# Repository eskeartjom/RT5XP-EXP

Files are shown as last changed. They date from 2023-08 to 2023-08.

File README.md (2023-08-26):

# RT5XP-EXP
A input expander for the RetroTINK 5X-Pro

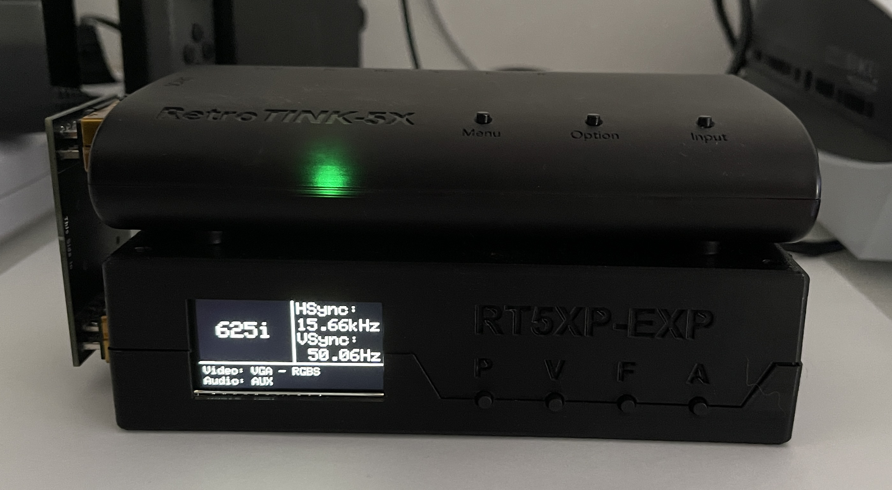
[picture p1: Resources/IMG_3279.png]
RT5XP-EXP

RT5XP-EXP Top

---
## Introduction
The RT5XP-EXP is a purpose build device to extend the input capabilities of the RetroTINK 5X-Pro.

### Input
The Following video signals are supported:

- SCART (RGBS, RGsB, YPbPr)
- Component (YPbPr, RGsB)
- VGA (RGBHV, RGBS, RGsB, YPbPr)

Audio signals can be input as RCA, 3.5mm Jack or SCART and can be selected independently of the video signal.

The sync on scart and component inputs need to be attenuated 75 Ohm signals.
Scart also supports a attenuated CSync signal as the sync input.

The VGA input only supports TTL signals on the sync pins. When using RGsB/YPbPr these need attenuated correctly (which they should be in the first place). VGA also supports TTL CSync on pin 13.

**Input Resolution***: 240p - 1080i

Switching between resolutions is seamless.

### Output

The RT5XP-EXP outputs the signal in RGBS format out of the left scart connector. This signal should be safe to plug into any scart device. The sync signal is a attenuated csync signal.

**Output Resolution***: 240p - 1080i

*Tested on a RetroTINK 5X-Pro and a OSSC

### Display
The big area on the top left shows the line count* of the current input.
The area on the right shows the measured* horizontal and vertical sync signal.
At the bottom the display shows the currenty used and video and audio input.

*The values may not be 100% accurate but close enough.

### Buttons
- P: Cycles thought presets.
- V: Cycles thought different video inputs.
- F: Cycles thought different formats of the current video input.
- A: Cycles thought different audio inputs.

Holding the P button opens a menu. This menu is still WIP.

---
## Hardware
The hardware consists of following things:

- [Main PCB](./Hardware/MainPCB)
- [Display bracked PCB](./Hardware/DisplayPCB)
- [Case](./Hardware/Case)
- [(Optional) SCART PCB](./Hardware/InterconnectPCB)
- [Display](https://www.adafruit.com/product/5394)

---
## Firmware
NOTE: Is still WIP but usable for the basics
- [Firmware](./Firmware)

The firmware is based on a ATmega4809.
I used the Arduino IDE with following libraries:
- [MegaCoreX](https://github.com/MCUdude/MegaCoreX)
- [Adafruit_ST7789](https://github.com/adafruit/Adafruit-ST7735-Library)
- [Adafruit_GFX](https://learn.adafruit.com/adafruit-gfx-graphics-library/overview)

The microcontroller can be flashed via the usb connection.

---
## Misc
Technically the RT5XP-EXP should be support 1080p resolution but i could not test it.

---
## Known issues
On sharp edges there is a purple "color bending". In game this isn't that noticable or might not be noticed at all.

Color Bending

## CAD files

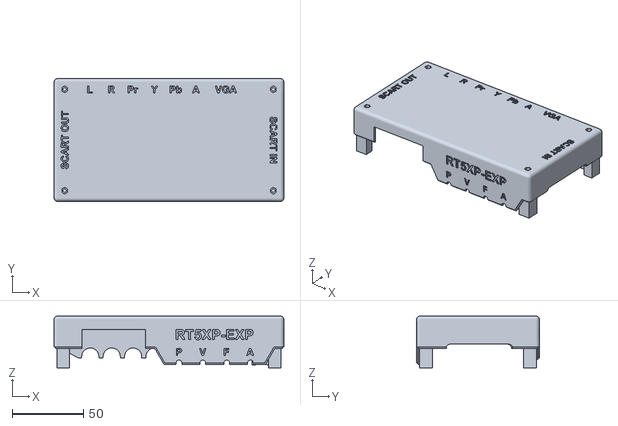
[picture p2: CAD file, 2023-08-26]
Hardware/Case/RT5XP-Top.stl
161.0 x 86.0 x 36.4

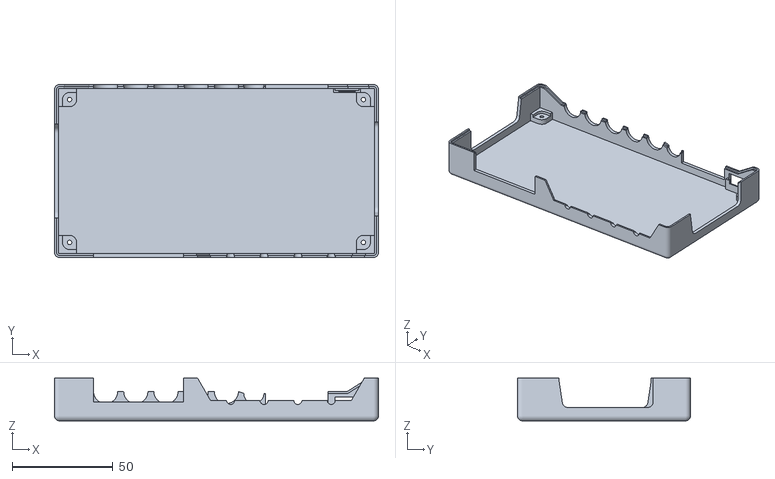
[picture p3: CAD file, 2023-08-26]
Hardware/Case/RT5XP-Bottom.stl
161.0 x 86.0 x 21.2

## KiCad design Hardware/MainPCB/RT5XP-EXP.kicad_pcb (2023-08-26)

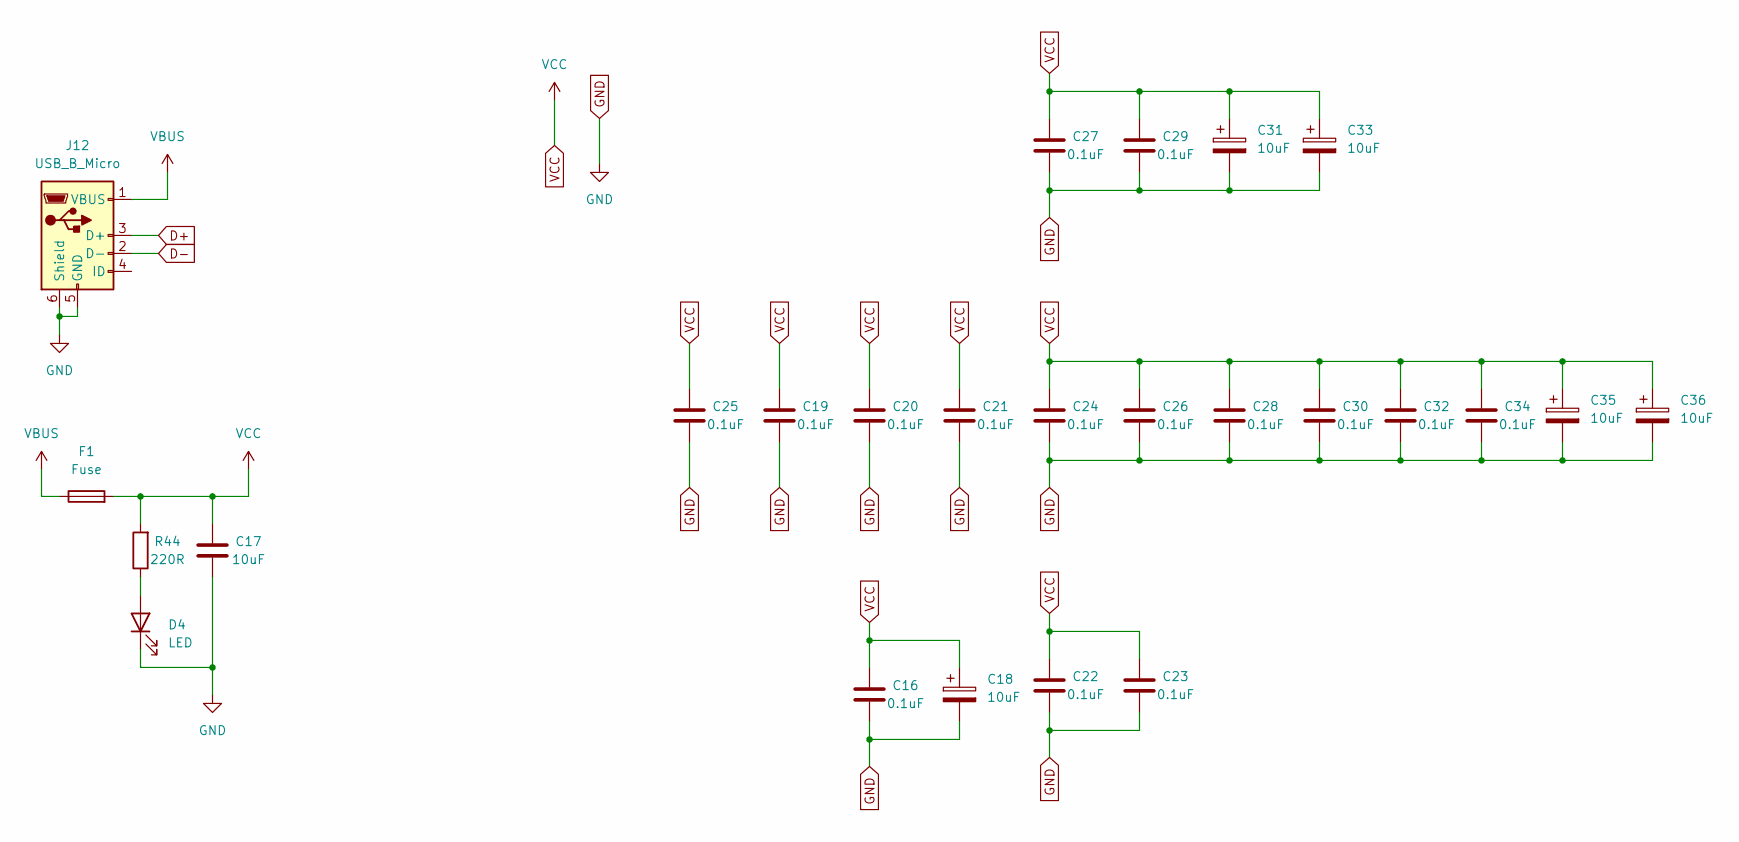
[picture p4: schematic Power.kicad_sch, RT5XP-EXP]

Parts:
C16, C19, C20, C21, C22, C23, C24, C25, C26, C27, C28, C29, C30, C32, C34: 0.1uF; C_0603_1608Metric
C17: 10uF; C_0805_2012Metric
C18, C31, C33, C35, C36: 10uF; C_0603_1608Metric
D4: LED; LED_0603_1608Metric
F1: Fuse; Fuse_1210_3225Metric
J12: USB_B_Micro; USB_Micro-B_Molex-105017-0001
R44: 220R; R_0603_1608Metric

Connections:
D+: J12.3 (D+); also elsewhere on the board
D-: J12.2 (D-); also elsewhere on the board
GND: C16.1, C17.1, C18.2, C19.1, C20.1, C21.1, C22.1, C23.1, C24.1, C25.1, C26.1, C27.1, C28.1, C29.1, C30.1, C31.2, C32.1, C33.2, C34.1, C35.2, C36.2, D4.1 (K), J12.5 (GND), J12.6 (Shield); also elsewhere on the board
unnamed: D4.2 (A), R44.1
VBUS: F1.1, J12.1 (VBUS)
VCC: C16.2, C17.2, C18.1, C19.2, C20.2, C21.2, C22.2, C23.2, C24.2, C25.2, C26.2, C27.2, C28.2, C29.2, C30.2, C31.1, C32.2, C33.1, C34.2, C35.1, C36.1, F1.2, R44.2; also elsewhere on the board

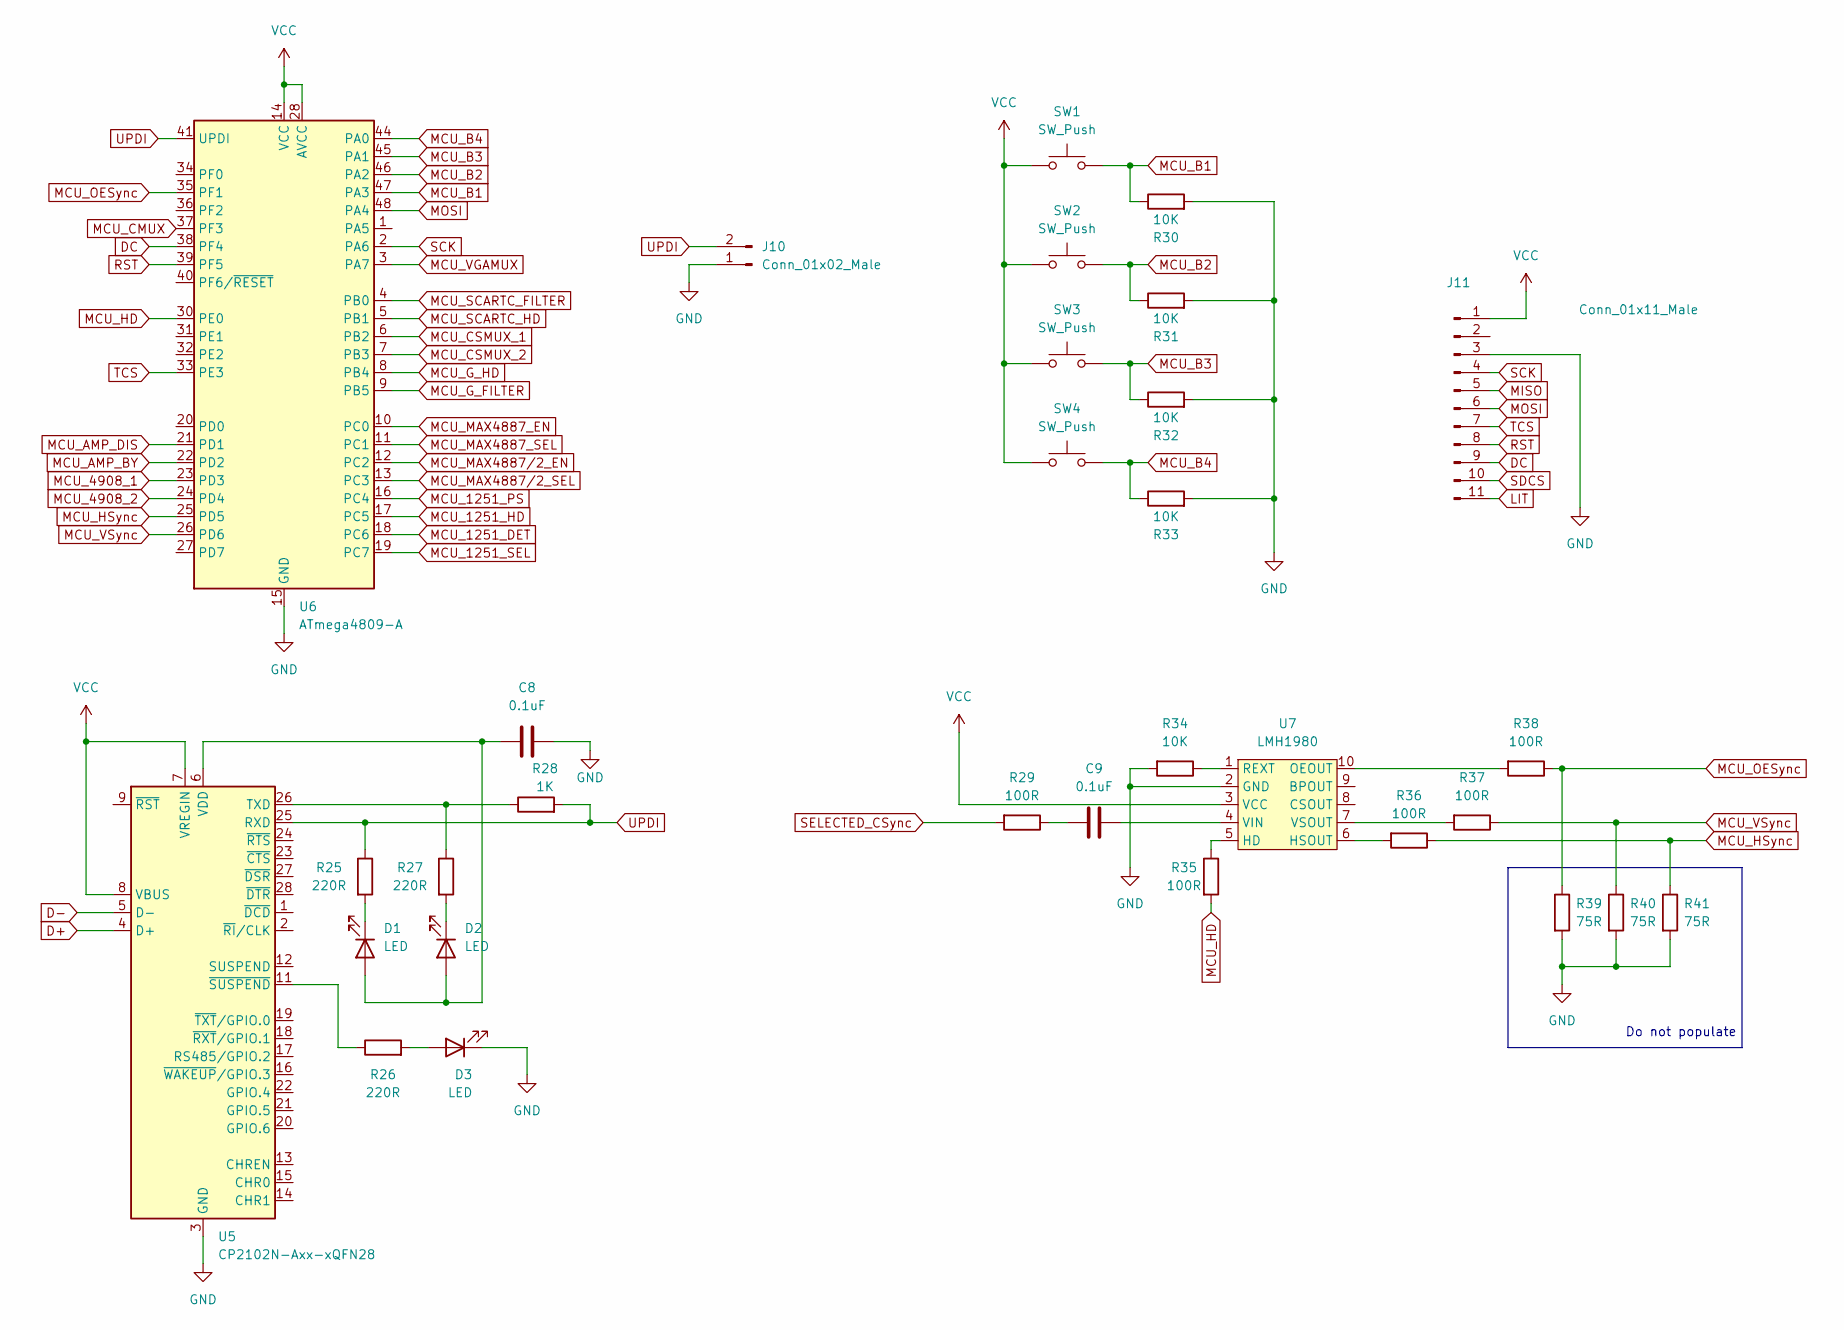
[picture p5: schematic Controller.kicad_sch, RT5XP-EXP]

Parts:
C8, C9: 0.1uF; C_0603_1608Metric
D1, D2, D3: LED; LED_0603_1608Metric
J10: Conn_01x02_Male; PinSocket_1x02_P2.54mm_Vertical
J11: Conn_01x11_Male; PinHeader_1x11_P2.54mm_Horizontal
R25, R26, R27: 220R; R_0603_1608Metric
R28: 1K; R_0603_1608Metric
R29, R35, R36, R37, R38: 100R; R_0603_1608Metric
R30, R31, R32, R33, R34: 10K; R_0603_1608Metric
R39, R40, R41: 75R; R_0603_1608Metric
SW1, SW2, SW3, SW4: SW_Push; SW_Tactile_SPST_Angled_PTS645Vx83-2LFS
U5: CP2102N-Axx-xQFN28; QFN-28-1EP_5x5mm_P0.5mm_EP3.35x3.35mm
U6: ATmega4809-A; TQFP-48_7x7mm_P0.5mm
U7: LMH1980; VSSOP-10_3x3mm_P0.5mm

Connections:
D+: U5.4 (D+); also elsewhere on the board
D-: U5.5 (D-); also elsewhere on the board
DC: J11.9, U6.38 (PF4)
GND: C8.1, D3.1 (K), J10.1, J11.3, R30.2, R31.2, R32.2, R33.2, R34.2, R39.2, R40.2, R41.2, U5.3 (GND), U5.29 (GND), U6.15 (GND), U6.29 (GND), U6.43 (GND), U7.2 (GND); also elsewhere on the board
LIT: J11.11
MCU_1251_DET: U6.18 (PC6); also elsewhere on the board
MCU_1251_HD: U6.17 (PC5); also elsewhere on the board
MCU_1251_PS: U6.16 (PC4); also elsewhere on the board
MCU_1251_SEL: U6.19 (PC7); also elsewhere on the board
MCU_4908_1: U6.23 (PD3); also elsewhere on the board
MCU_4908_2: U6.24 (PD4); also elsewhere on the board
MCU_AMP_BY: U6.22 (PD2); also elsewhere on the board
MCU_AMP_DIS: U6.21 (PD1); also elsewhere on the board
MCU_B1: R30.1, SW1.2, U6.47 (PA3)
MCU_B2: R31.1, SW2.2, U6.46 (PA2)
MCU_B3: R32.1, SW3.2, U6.45 (PA1)
MCU_B4: R33.1, SW4.2, U6.44 (PA0)
MCU_CMUX: U6.37 (PF3); also elsewhere on the board
MCU_CSMUX_1: U6.6 (PB2); also elsewhere on the board
MCU_CSMUX_2: U6.7 (PB3); also elsewhere on the board
MCU_G_FILTER: U6.9 (PB5); also elsewhere on the board
MCU_G_HD: U6.8 (PB4); also elsewhere on the board
MCU_HD: R35.2, U6.30 (PE0)
MCU_HSync: R36.1, R41.1, U6.25 (PD5)
MCU_MAX4887_EN: U6.10 (PC0); also elsewhere on the board
MCU_MAX4887_SEL: U6.11 (PC1); also elsewhere on the board
MCU_MAX4887/2_EN: U6.12 (PC2); also elsewhere on the board
MCU_MAX4887/2_SEL: U6.13 (PC3); also elsewhere on the board
MCU_OESync: R38.1, R39.1, U6.35 (PF1)
MCU_SCARTC_FILTER: U6.4 (PB0); also elsewhere on the board
MCU_SCARTC_HD: U6.5 (PB1); also elsewhere on the board
MCU_VGAMUX: U6.3 (PA7); also elsewhere on the board
MCU_VSync: R37.1, R40.1, U6.26 (PD6)
MISO: J11.5
MOSI: J11.6, U6.48 (PA4)
unnamed: C8.2, D1.2 (A), D2.2 (A), U5.6 (VDD)
unnamed: C9.1, R29.1
unnamed: C9.2, U7.4 (VIN)
unnamed: D1.1 (K), R25.2
unnamed: D2.1 (K), R27.2
unnamed: D3.2 (A), R26.2
unnamed: R26.1, U5.11 (~SUSPEND)
unnamed: R27.1, R28.1, U5.26 (TXD)
unnamed: R34.1, U7.1 (REXT)
unnamed: R35.1, U7.5 (HD)
unnamed: R36.2, U7.6 (HSOUT)
unnamed: R37.2, U7.7 (VSOUT)
unnamed: R38.2, U7.10 (OEOUT)
RST: J11.8, U6.39 (PF5)
SCK: J11.4, U6.2 (PA6)
SDCS: J11.10
SELECTED_CSync: R29.2; also elsewhere on the board
TCS: J11.7, U6.33 (PE3)
UPDI: J10.2, R25.1, R28.2, U5.25 (RXD), U6.41 (UPDI)
VCC: J11.1, SW1.1, SW2.1, SW3.1, SW4.1, U5.7 (VREGIN), U5.8 (VBUS), U6.14 (VCC), U6.28 (AVCC), U6.42 (VCC), U7.3 (VCC); also elsewhere on the board

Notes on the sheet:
Do not populate

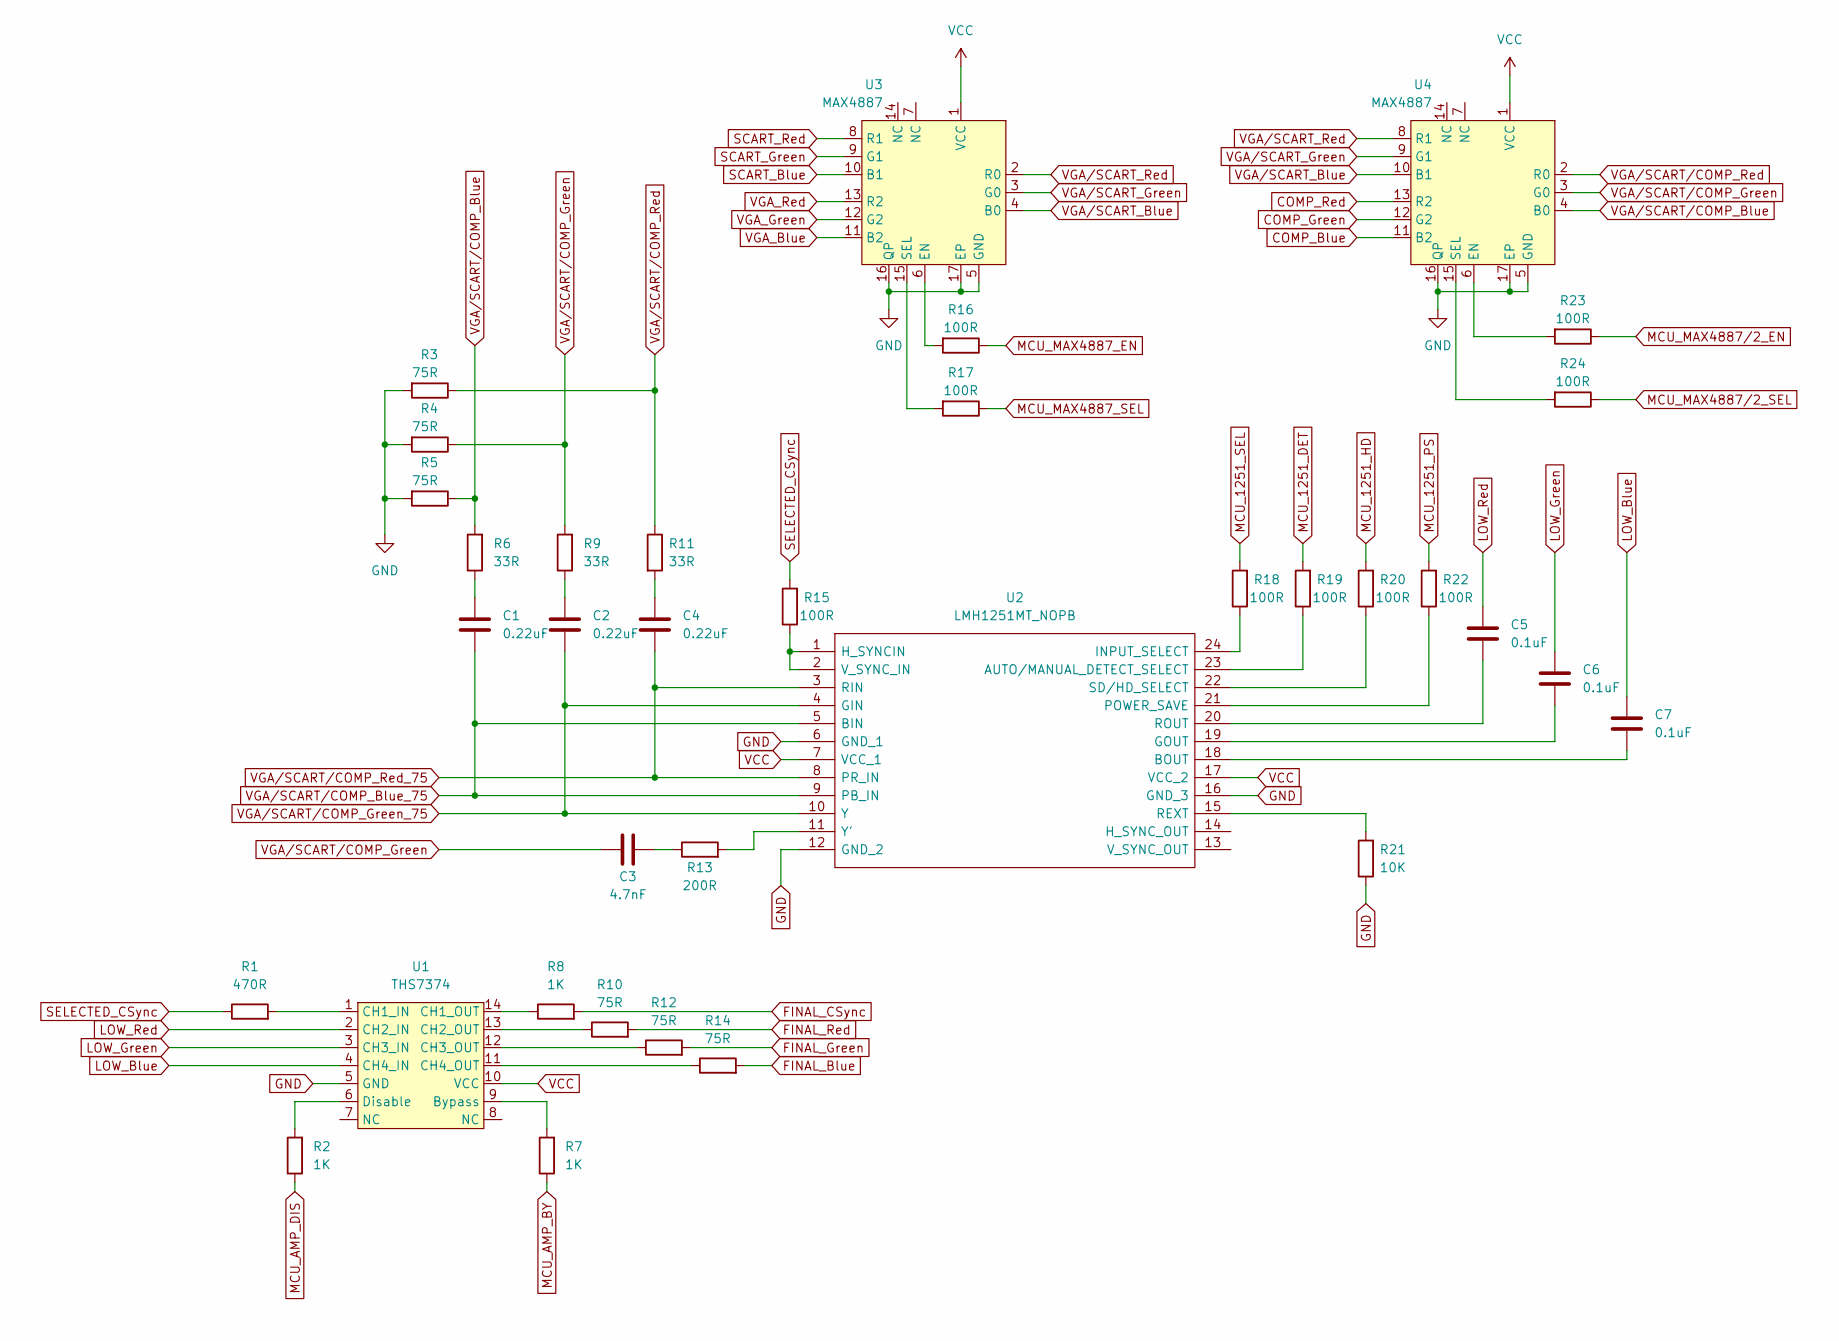
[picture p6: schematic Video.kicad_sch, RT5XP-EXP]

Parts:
C1, C2, C4: 0.22uF; C_0603_1608Metric
C3: 4.7nF; C_0603_1608Metric
C5, C6, C7: 0.1uF; C_0603_1608Metric
R1: 470R; R_0603_1608Metric
R2, R7, R8: 1K; R_0603_1608Metric
R3, R4, R5, R10, R12, R14: 75R; R_0603_1608Metric
R6, R9, R11: 33R; R_0603_1608Metric
R13: 200R; R_0603_1608Metric
R15, R16, R17, R18, R19, R20, R22, R23, R24: 100R; R_0603_1608Metric
R21: 10K; R_0603_1608Metric
U1: THS7374; TSSOP-14_4.4x5mm_P0.65mm
U2: LMH1251MT_NOPB; TSSOP-24_4.4x7.8mm_P0.65mm; Mouser Part Number 926-LMH1251MT/NOPB
U3, U4: MAX4887; TQFN-16-1EP_3x3mm_P0.5mm_EP1.23x1.23mm

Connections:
COMP_Blue: U4.11 (B2); also elsewhere on the board
COMP_Green: U4.12 (G2); also elsewhere on the board
COMP_Red: U4.13 (R2); also elsewhere on the board
FINAL_Blue: R14.2; also elsewhere on the board
FINAL_CSync: R8.2; also elsewhere on the board
FINAL_Green: R12.2; also elsewhere on the board
FINAL_Red: R10.2; also elsewhere on the board
GND: R3.2, R4.2, R5.2, R21.1, U1.5 (GND), U2.6 (GND_1), U2.12 (GND_2), U2.16 (GND_3), U3.5 (GND), U3.16 (QP), U3.17 (EP), U4.5 (GND), U4.16 (QP), U4.17 (EP); also elsewhere on the board
LOW_Blue: C7.2, U1.4 (CH4_IN)
LOW_Green: C6.2, U1.3 (CH3_IN)
LOW_Red: C5.2, U1.2 (CH2_IN)
MCU_1251_DET: R19.2; also elsewhere on the board
MCU_1251_HD: R20.2; also elsewhere on the board
MCU_1251_PS: R22.2; also elsewhere on the board
MCU_1251_SEL: R18.2; also elsewhere on the board
MCU_AMP_BY: R7.1; also elsewhere on the board
MCU_AMP_DIS: R2.1; also elsewhere on the board
MCU_MAX4887_EN: R16.1; also elsewhere on the board
MCU_MAX4887_SEL: R17.1; also elsewhere on the board
MCU_MAX4887/2_EN: R23.1; also elsewhere on the board
MCU_MAX4887/2_SEL: R24.1; also elsewhere on the board
unnamed: C1.2, R6.1
unnamed: C2.2, R9.1
unnamed: C3.2, R13.1
unnamed: C4.2, R11.2
unnamed: C5.1, U2.20 (ROUT)
unnamed: C6.1, U2.19 (GOUT)
unnamed: C7.1, U2.18 (BOUT)
unnamed: R1.2, U1.1 (CH1_IN)
unnamed: R2.2, U1.6 (Disable)
unnamed: R7.2, U1.9 (Bypass)
unnamed: R8.1, U1.14 (CH1_OUT)
unnamed: R10.1, U1.13 (CH2_OUT)
unnamed: R12.1, U1.12 (CH3_OUT)
unnamed: R13.2, U2.11 (Y')
unnamed: R14.1, U1.11 (CH4_OUT)
unnamed: R15.1, U2.1 (H_SYNCIN), U2.2 (V_SYNC_IN)
unnamed: R16.2, U3.6 (EN)
unnamed: R17.2, U3.15 (SEL)
unnamed: R18.1, U2.24 (INPUT_SELECT)
unnamed: R19.1, U2.23 (AUTO/MANUAL_DETECT_SELECT)
unnamed: R20.1, U2.22 (SD/HD_SELECT~)
unnamed: R21.2, U2.15 (REXT)
unnamed: R22.1, U2.21 (POWER_SAVE)
unnamed: R23.2, U4.6 (EN)
unnamed: R24.2, U4.15 (SEL)
SCART_Blue: U3.10 (B1); also elsewhere on the board
SCART_Green: U3.9 (G1); also elsewhere on the board
SCART_Red: U3.8 (R1); also elsewhere on the board
SELECTED_CSync: R1.1, R15.2; also elsewhere on the board
VCC: U1.10 (VCC), U2.7 (VCC_1), U2.17 (VCC_2), U3.1 (VCC), U4.1 (VCC); also elsewhere on the board
VGA_Blue: U3.11 (B2); also elsewhere on the board
VGA_Green: U3.12 (G2); also elsewhere on the board
VGA_Red: U3.13 (R2); also elsewhere on the board
VGA/SCART_Blue: U3.4 (B0), U4.10 (B1)
VGA/SCART_Green: U3.3 (G0), U4.9 (G1)
VGA/SCART_Red: U3.2 (R0), U4.8 (R1)
VGA/SCART/COMP_Blue: R5.1, R6.2, U4.4 (B0)
VGA/SCART/COMP_Blue_75: C1.1, U2.5 (BIN), U2.9 (PB_IN)
VGA/SCART/COMP_Green: C3.1, R4.1, R9.2, U4.3 (G0)
VGA/SCART/COMP_Green_75: C2.1, U2.4 (GIN), U2.10 (Y); also elsewhere on the board
VGA/SCART/COMP_Red: R3.1, R11.1, U4.2 (R0)
VGA/SCART/COMP_Red_75: C4.1, U2.3 (RIN), U2.8 (PR_IN)

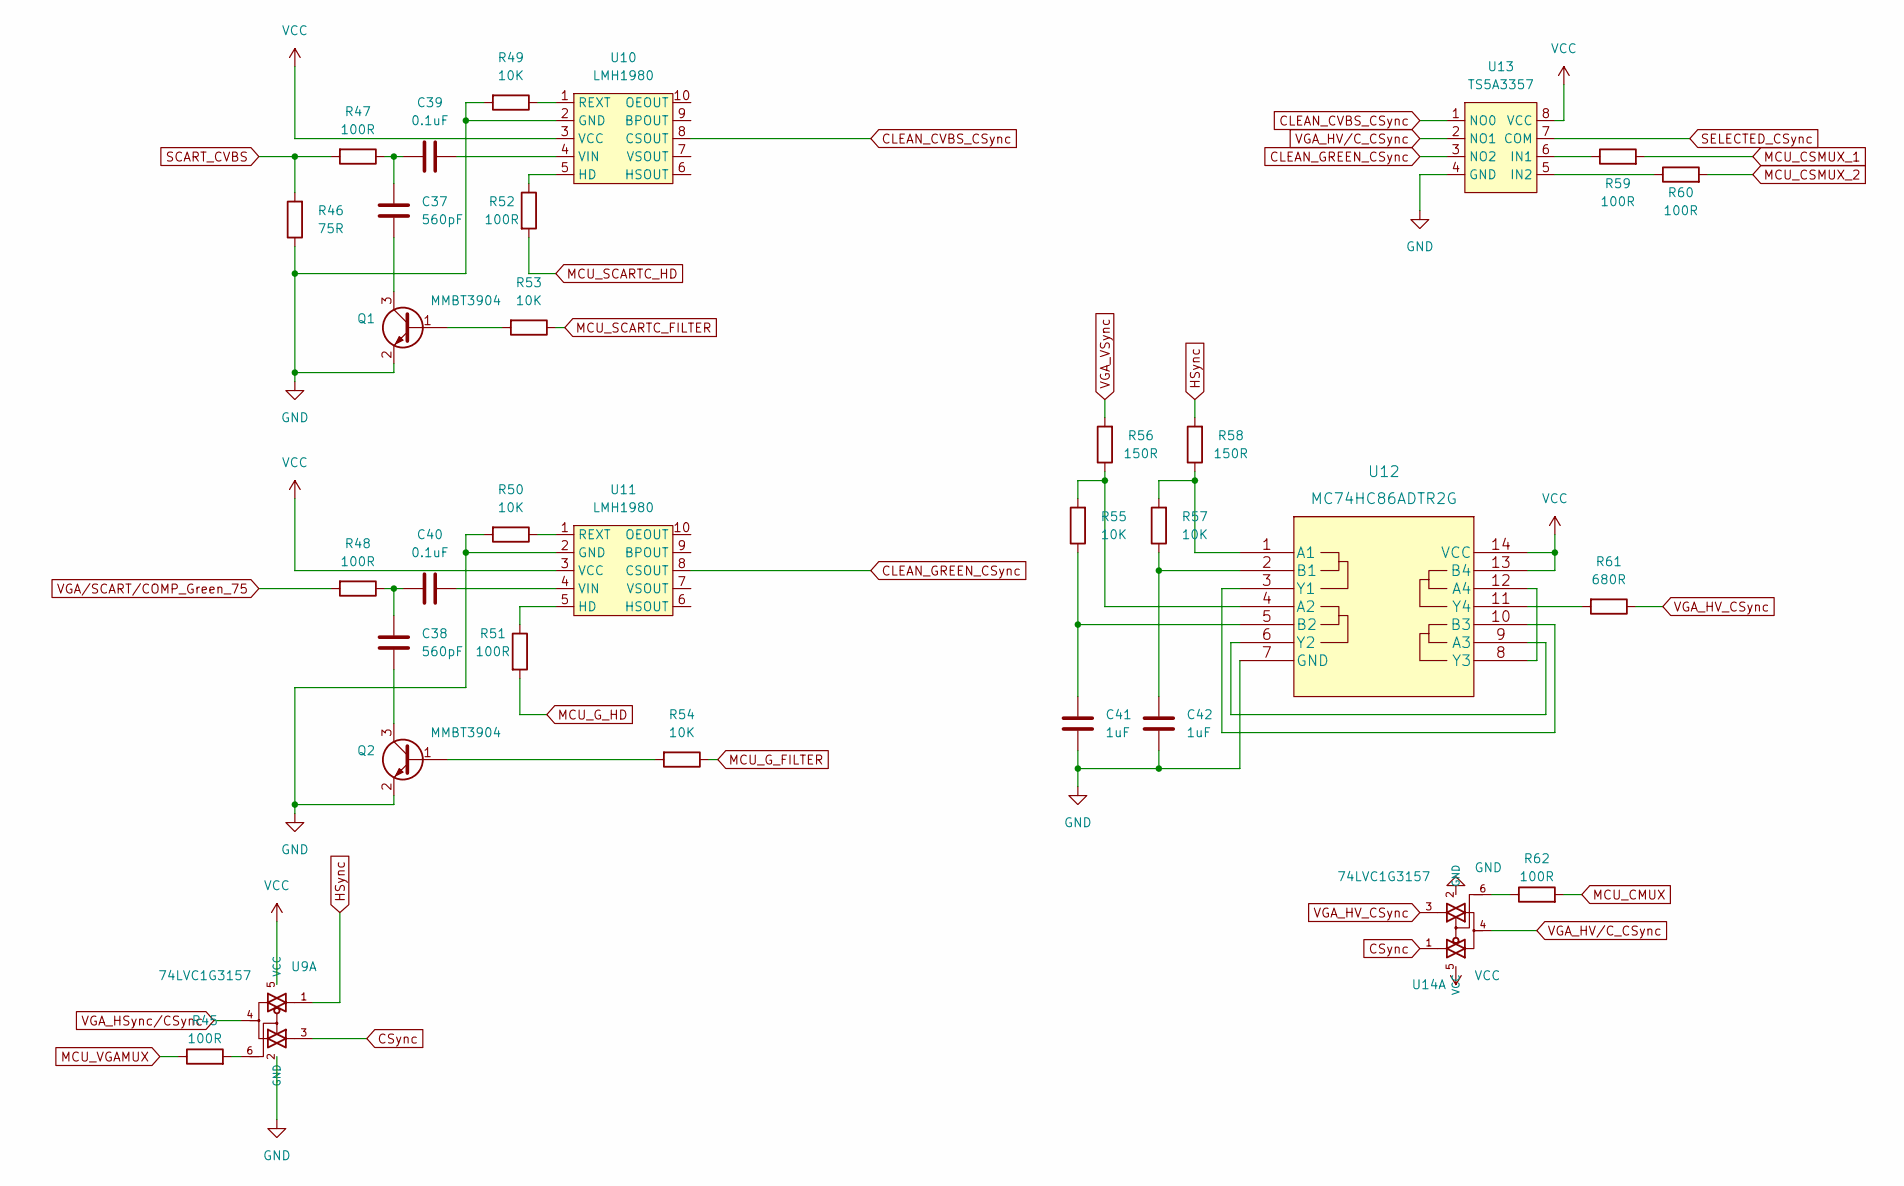
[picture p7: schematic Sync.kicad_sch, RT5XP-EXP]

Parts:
C37, C38: 560pF; C_0603_1608Metric
C39, C40: 0.1uF; C_0603_1608Metric
C41, C42: 1uF; C_0603_1608Metric
Q1, Q2: MMBT3904; SOT-23
R45, R47, R48, R51, R52, R59, R60, R62: 100R; R_0603_1608Metric
R46: 75R; R_0603_1608Metric
R49, R50, R53, R54, R55, R57: 10K; R_0603_1608Metric
R56, R58: 150R; R_0603_1608Metric
R61: 680R; R_0603_1608Metric
U9, U14: 74LVC1G3157; TSOT-23-6
U10, U11: LMH1980; VSSOP-10_3x3mm_P0.5mm
U12: MC74HC86ADTR2G; TSSOP-14_4.4x5mm_P0.65mm
U13: TS5A3357; VSSOP-8_2.3x2mm_P0.5mm

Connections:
CLEAN_CVBS_CSync: U10.8 (CSOUT), U13.1 (NO0)
CLEAN_GREEN_CSync: U11.8 (CSOUT), U13.3 (NO2)
CSync: U9.3, U14.1
GND: C41.1, C42.1, Q1.2 (E), Q2.2 (E), R46.1, R49.2, R50.2, U9.2 (GND), U10.2 (GND), U11.2 (GND), U12.7 (GND), U13.4 (GND), U14.2 (GND); also elsewhere on the board
HSync: R58.2, U9.1
MCU_CMUX: R62.2; also elsewhere on the board
MCU_CSMUX_1: R59.2; also elsewhere on the board
MCU_CSMUX_2: R60.2; also elsewhere on the board
MCU_G_FILTER: R54.1; also elsewhere on the board
MCU_G_HD: R51.2; also elsewhere on the board
MCU_SCARTC_FILTER: R53.1; also elsewhere on the board
MCU_SCARTC_HD: R52.2; also elsewhere on the board
MCU_VGAMUX: R45.1; also elsewhere on the board
unnamed: C37.1, Q1.3 (C)
unnamed: C37.2, C39.1, R47.1
unnamed: C38.1, Q2.3 (C)
unnamed: C38.2, C40.1, R48.1
unnamed: C39.2, U10.4 (VIN)
unnamed: C40.2, U11.4 (VIN)
unnamed: C41.2, R55.1, U12.5 (B2)
unnamed: C42.2, R57.1, U12.2 (B1)
unnamed: Q1.1 (B), R53.2
unnamed: Q2.1 (B), R54.2
unnamed: R45.2, U9.6
unnamed: R49.1, U10.1 (REXT)
unnamed: R50.1, U11.1 (REXT)
unnamed: R51.1, U11.5 (HD)
unnamed: R52.1, U10.5 (HD)
unnamed: R55.2, R56.1, U12.4 (A2)
unnamed: R57.2, R58.1, U12.1 (A1)
unnamed: R59.1, U13.6 (IN1)
unnamed: R60.1, U13.5 (IN2)
unnamed: R61.2, U12.11 (Y4)
unnamed: R62.1, U14.6
unnamed: U12.6 (Y2), U12.9 (A3)
unnamed: U12.3 (Y1), U12.10 (B3)
unnamed: U12.8 (Y3), U12.12 (A4)
SCART_CVBS: R46.2, R47.2; also elsewhere on the board
SELECTED_CSync: U13.7 (COM); also elsewhere on the board
VCC: U9.5 (VCC), U10.3 (VCC), U11.3 (VCC), U12.13 (B4), U12.14 (VCC), U13.8 (VCC), U14.5 (VCC); also elsewhere on the board
VGA_HSync/CSync: U9.4; also elsewhere on the board
VGA_HV_CSync: R61.1, U14.3
VGA_HV/C_CSync: U13.2 (NO1), U14.4
VGA_VSync: R56.2; also elsewhere on the board
VGA/SCART/COMP_Green_75: R48.2; also elsewhere on the board

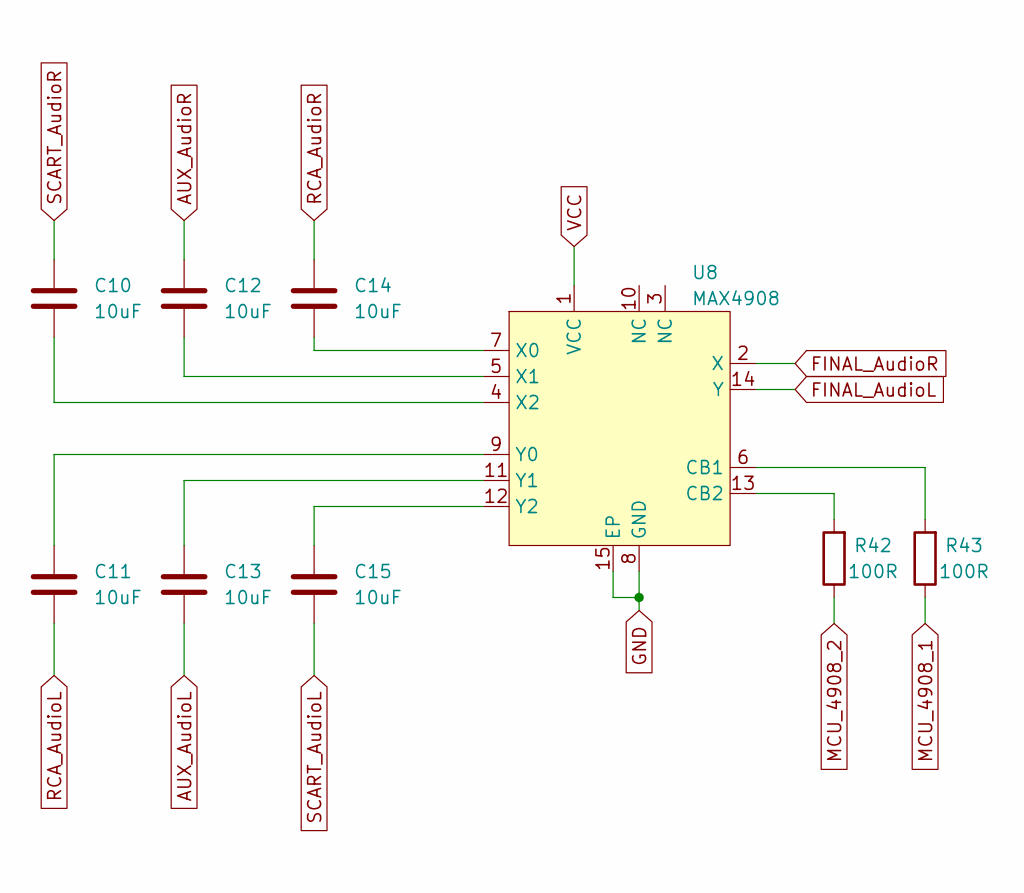
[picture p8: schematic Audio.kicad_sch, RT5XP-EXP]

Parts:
C10, C11, C12, C13, C14, C15: 10uF; C_0603_1608Metric
R42, R43: 100R; R_0603_1608Metric
U8: MAX4908; TDFN-14-1EP_3x3mm_P0.4mm_EP1.78x2.35mm

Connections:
AUX_AudioL: C13.1; also elsewhere on the board
AUX_AudioR: C12.2; also elsewhere on the board
FINAL_AudioL: U8.14 (Y); also elsewhere on the board
FINAL_AudioR: U8.2 (X); also elsewhere on the board
GND: U8.8 (GND), U8.15 (EP); also elsewhere on the board
MCU_4908_1: R43.1; also elsewhere on the board
MCU_4908_2: R42.1; also elsewhere on the board
unnamed: C10.1, U8.4 (X2)
unnamed: C11.2, U8.9 (Y0)
unnamed: C12.1, U8.5 (X1)
unnamed: C13.2, U8.11 (Y1)
unnamed: C14.1, U8.7 (X0)
unnamed: C15.2, U8.12 (Y2)
unnamed: R42.2, U8.13 (CB2)
unnamed: R43.2, U8.6 (CB1)
RCA_AudioL: C11.1; also elsewhere on the board
RCA_AudioR: C14.2; also elsewhere on the board
SCART_AudioL: C15.1; also elsewhere on the board
SCART_AudioR: C10.2; also elsewhere on the board
VCC: U8.1 (VCC); also elsewhere on the board

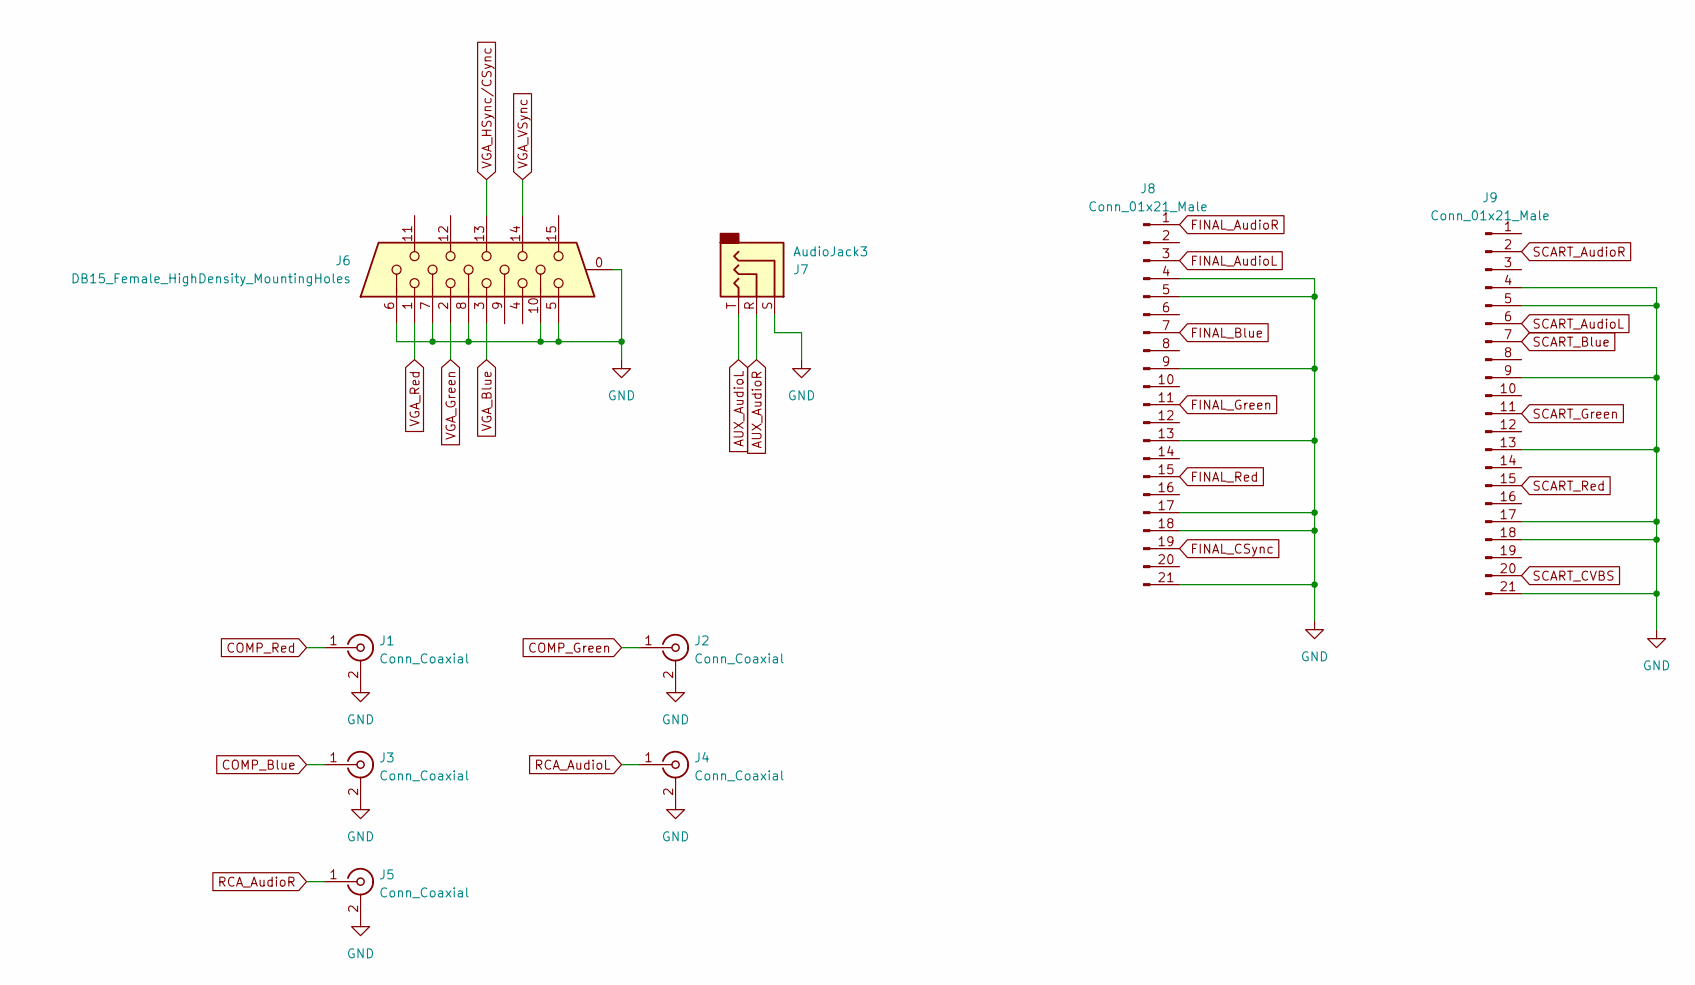
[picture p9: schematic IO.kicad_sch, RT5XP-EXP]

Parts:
J1, J2, J3, J4, J5: Conn_Coaxial; PJRAN1X1U02AUX
J6: DB15_Female_HighDensity_MountingHoles; L77HDE15SD1CH4RHNVGA
J7: AudioJack3; Jack_3.5mm_CUI_SJ1-3535NG_Horizontal
J8, J9: Conn_01x21_Male; SCART

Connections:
AUX_AudioL: J7.T; also elsewhere on the board
AUX_AudioR: J7.R; also elsewhere on the board
COMP_Blue: J3.1 (In); also elsewhere on the board
COMP_Green: J2.1 (In); also elsewhere on the board
COMP_Red: J1.1 (In); also elsewhere on the board
FINAL_AudioL: J8.3; also elsewhere on the board
FINAL_AudioR: J8.1; also elsewhere on the board
FINAL_Blue: J8.7; also elsewhere on the board
FINAL_CSync: J8.19; also elsewhere on the board
FINAL_Green: J8.11; also elsewhere on the board
FINAL_Red: J8.15; also elsewhere on the board
GND: J1.2 (Ext), J2.2 (Ext), J3.2 (Ext), J4.2 (Ext), J5.2 (Ext), J6.0, J6.5, J6.6, J6.7, J6.8, J6.10, J7.S, J8.4, J8.5, J8.9, J8.13, J8.17, J8.18, J8.21, J9.4, J9.5, J9.9, J9.13, J9.17, J9.18, J9.21; also elsewhere on the board
RCA_AudioL: J4.1 (In); also elsewhere on the board
RCA_AudioR: J5.1 (In); also elsewhere on the board
SCART_AudioL: J9.6; also elsewhere on the board
SCART_AudioR: J9.2; also elsewhere on the board
SCART_Blue: J9.7; also elsewhere on the board
SCART_CVBS: J9.20; also elsewhere on the board
SCART_Green: J9.11; also elsewhere on the board
SCART_Red: J9.15; also elsewhere on the board
VGA_Blue: J6.3; also elsewhere on the board
VGA_Green: J6.2; also elsewhere on the board
VGA_HSync/CSync: J6.13; also elsewhere on the board
VGA_Red: J6.1; also elsewhere on the board
VGA_VSync: J6.14; also elsewhere on the board

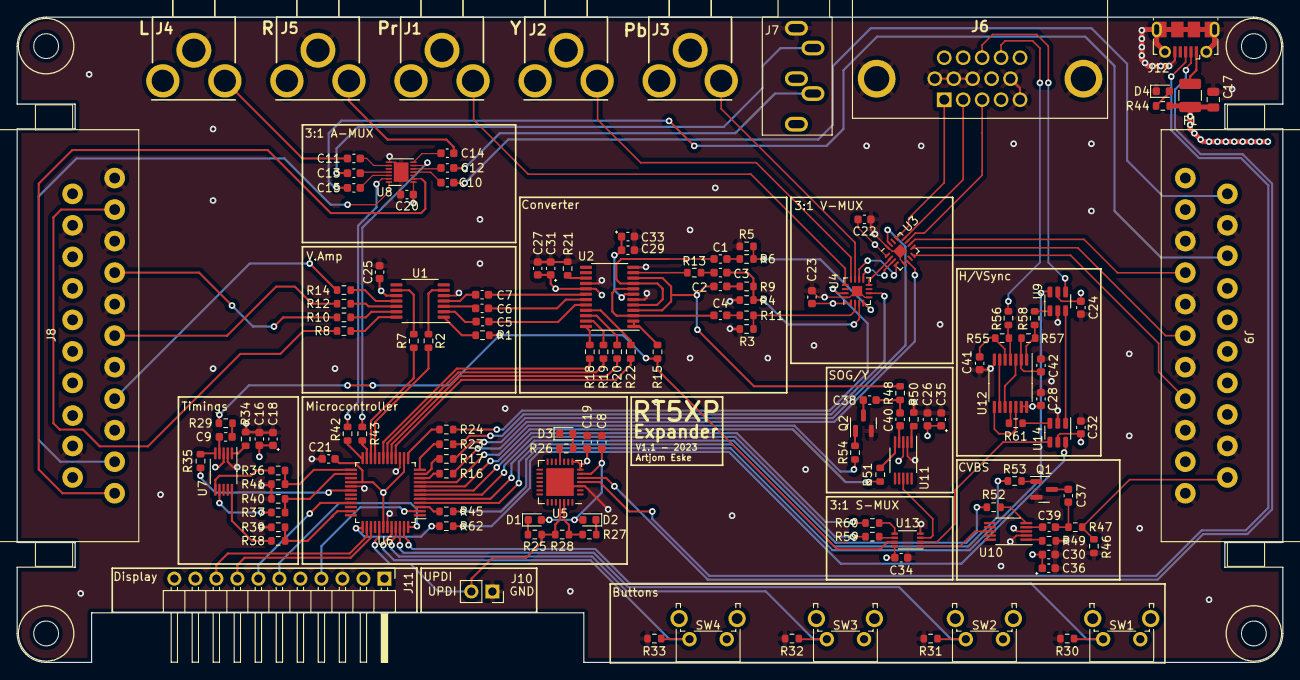
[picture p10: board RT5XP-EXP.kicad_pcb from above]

Board: 4 copper layers, 153.0 x 78.0 mm, 141 parts (0 on the bottom side), 153 nets.

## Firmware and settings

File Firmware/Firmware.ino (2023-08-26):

/**************************************************************************
#define PIN_PA0 0 RX_CP2102
#define PIN_PA1 1 TX_CP2102
#define PIN_PA2 2
#define PIN_PA3 3
#define PIN_PA4 4 MOSI_Display
#define PIN_PA5 5
#define PIN_PA6 6 SCK_Display
#define PIN_PA7 7
#define PIN_PB0 8
#define PIN_PB1 9
#define PIN_PB2 10
#define PIN_PB3 11
#define PIN_PB4 12
#define PIN_PB5 13
#define PIN_PC0 14
#define PIN_PC1 15
#define PIN_PC2 16
#define PIN_PC3 17
#define PIN_PC4 18
#define PIN_PC5 19
#define PIN_PC6 20
#define PIN_PC7 21
#define PIN_PD0 22
#define PIN_PD1 23
#define PIN_PD2 24
#define PIN_PD3 25
#define PIN_PD4 26
#define PIN_PD5 27 HSync
#define PIN_PD6 28 VSync
#define PIN_PD7 29 
#define PIN_PE0 30
#define PIN_PE1 31
#define PIN_PE2 32
#define PIN_PE3 33 TCS_Display
#define PIN_PF0 34
#define PIN_PF1 35 Odd/Even
#define PIN_PF2 36
#define PIN_PF3 37
#define PIN_PF4 38 DC_Display
#define PIN_PF5 39 RST_Display
#define PIN_PF6 40 CP2021


BITMAP 4Byte / 32 Bit - int32_t

00000000 00000000 00000000 00000000

SCART RGBS  = XXXXXXXX XXXXXXXX XXXX0000 0X100100
SCART YPbPr = XXXXXXXX XXXXXXXX XXXX0000 0X111100
SCART RGsB  = XXXXXXXX XXXXXXXX XXXX0000 0X110100

COMP YPbPr  = XXXXXXXX XXXXXXXX XXXX1000 0X111100
COMP RGsB   = XXXXXXXX XXXXXXXX XXXX1000 0X110100

VGA RGBHV   = XXXXXXXX XXXXXXXX XX010010 0X101000

**************************************************************************/

#include <Adafruit_GFX.h>     // Core graphics library
#include <Adafruit_ST7789.h>  // Hardware-specific library for ST7789
#include <SPI.h>
#include <avr/io.h>
#include <math.h>
#include <avr/interrupt.h>
#include <util/atomic.h>

#include "Button.h"
#include "Timer.h"

#define VIDEO_AMP_BYPASS 24
#define VIDEO_AMP_DISABLE 23

#define CONVERTER_SELECT 21
#define CONVERTER_DETECT 20
#define CONVERTER_HD 19
#define CONVERTER_POWERSAVE 18

#define VIDEO_MUX_1_ENABLE 14
#define VIDEO_MUX_1_SELECT 15
#define VIDEO_MUX_2_ENABLE 16
#define VIDEO_MUX_2_SELECT 17

#define CSYNC_MUX_1 10
#define CSYNC_MUX_2 11
#define HSYNC_MUX_IN 7
#define HSYNC_MUX_OUT 37

#define AUDIO_MUX_1 25
#define AUDIO_MUX_2 26

#define FG_COLOR 0xFFFF
#define BG_COLOR 0x0000
#define SL_COLOR 0xC409
#define HS_TEXT "HSync:"
#define VS_TEXT "VSync:"
#define VD_TEXT "Video: "
#define AD_TEXT "Audio: "
#define HZ_TEXT "Hz"
#define KHZ_TEXT "kHz"
#define PROGRESSIVE_TEXT "p"
#define INTERLACED_TEXT "i"
#define NO_SYNC_TEXT_1 "No"
#define NO_SYNC_TEXT_2 "Sync"

bool settingsMenu = false;

float tempHorizontalFreq = 0.0f;
float tempHorizontalPos = 0.0f;
float tempHorizontalNeg = 0.0f;

float tempVerticalFreq = 0.0f;
float tempVerticalPos = 0.0f;
float tempVerticalNeg = 0.0f;

float tempInterlacedFreq = 0.0f;
float tempInterlacedPos = 0.0f;
float tempInterlacedNeg = 0.0f;

Button But1(0);
Button But2(1);
Button But3(2);
Button But4(3);

Adafruit_ST7789 TFT = Adafruit_ST7789(33, 38, 39);

SoftwareTimer timingHSyncTimer;
SoftwareTimer timingVSyncTimer;
SoftwareTimer timingOddEvenTimer;

HardwareTimer<0> timerTCB0;
HardwareTimer<1> timerTCB1;
HardwareTimer<3> timerTCB3;


int8_t avSetting = 0b00110100;  // first nibble audio / last nibble video and format

bool videoPinsSet = false;
bool audioPinsSet = false;

int32_t selectedPreset = 0;



struct Timings {

  Timings() {}

public:
  float horizontal = 0.0f;
  float vertical = 0.0f;
  float interlaced = 0.0f;
  int32_t lineCount = 0;

  bool locked = false;

private:

  String lastPrinted = "";
  int32_t lastX = 0;
  int32_t lastY = 0;
  int32_t lastW = 0;
  int32_t lastH = 0;

public:

  setLinecount(int32_t count){
    if(lineCount == count)
      return;

    lineCount = count;

    if(locked)
      printLinecount();

  }

  setLock(bool state){

    if(locked == state)
      return;

    locked = state;

    if(!locked){
      lineCount = 0;
      printLinecount();
    }
    else
    {
      printLinecount();
    }
    
  }

private:

  void centerText(int32_t width, int32_t height, int32_t& x, int32_t& y, int32_t fontSize, String str){
    
    int32_t textWidth = strlen(str.c_str()) * 6 * fontSize;
    int32_t textHeight = 8 * fontSize;

    x = (width / 2 - textWidth / 2) + 1;
    y = height / 2 - textHeight / 2;

  }

  void printLinecount(){

    TFT.setTextColor(FG_COLOR);
    TFT.setTextSize(4);

    if(lineCount == 0 || !locked){
      if(lastPrinted == NO_SYNC_TEXT_1)
        return;
    }
    else if(String(lineCount) == lastPrinted)
      return;

    TFT.fillRect(lastX, lastY, lastW, lastH, BG_COLOR);

    if(lineCount == 0 || !locked){

      lastPrinted = NO_SYNC_TEXT_1;

      TFT.setCursor(58, 26);
      TFT.print(NO_SYNC_TEXT_1);
      TFT.setCursor(34, 62);
      TFT.print(NO_SYNC_TEXT_2);

      lastX = 34;
      lastY = 26;
      lastW = 96;
      lastH = 68;
      return;
    }

    String lcStr = "";

    if(interlaced != 0.0f)
      lcStr = String(lineCount) + INTERLACED_TEXT;
    else
      lcStr = String(lineCount) + PROGRESSIVE_TEXT;

    
    int32_t x;
    int32_t y;
    centerText(163, 120, x, y, 4, lcStr);

    lastPrinted = lcStr;
    lastX = x;
    lastY = y;
    lastW = strlen(lcStr.c_str()) * 6 * 4;
    lastH = 8 * 4;

    TFT.setCursor(x, y);
    TFT.print(lcStr);
  }
};

struct TimingSample {

  TimingSample() {}

  float horizontal = 0.0f;
  float vertical = 0.0f;
  float interlaced = 0.0f;
};

TimingSample timingSamples[10];
uint32_t tSampleIndex = 0;

Timings timings;

//{HW Timer
  void initEventSystem(void) {
    EVSYS.CHANNEL2 = EVSYS_GENERATOR_PORT1_PIN5_gc;  // connect Pin 'PD5' to channel 2
    EVSYS.USERTCB0 = EVSYS_CHANNEL_CHANNEL2_gc;      // connect 'generator 'PD5' with user 'TCB0' via channel 2

    EVSYS.CHANNEL3 = EVSYS_GENERATOR_PORT1_PIN6_gc;
    EVSYS.USERTCB1 = EVSYS_CHANNEL_CHANNEL3_gc;

    EVSYS.CHANNEL4 = EVSYS_GENERATOR_PORT1_PIN1_gc;
    EVSYS.USERTCB3 = EVSYS_CHANNEL_CHANNEL4_gc;
  }


  void initTCB0(void) {
    timerTCB0.Reset();
    timerTCB0.SetCLKDIV1();
    timerTCB0.SetModeFRQPW();
    timerTCB0.EnableEventInput();
    timerTCB0.EnableCAPTInterrupt();
    timerTCB0.Enable();
  }

  void initTCB1(void) {
    TCA0.SINGLE.CTRLA = TCA_SINGLE_CLKSEL_DIV64_gc | TCA_SINGLE_ENABLE_bm;
    timerTCB1.Reset();
    timerTCB1.SetCLKTCA();
    timerTCB1.SetModeFRQPW();
    timerTCB1.EnableEventInput();
    timerTCB1.EnableCAPTInterrupt();
    timerTCB1.Enable();
  }

  void initTCB3(void) {
    TCA0.SINGLE.CTRLA = TCA_SINGLE_CLKSEL_DIV64_gc | TCA_SINGLE_ENABLE_bm;
    timerTCB3.Reset();
    timerTCB3.SetCLKTCA();
    timerTCB3.SetModeFRQPW();
    timerTCB3.EnableEventInput();
    timerTCB3.EnableCAPTInterrupt();
    timerTCB3.Enable();
  }

  ISR(TCB0_INT_vect) {
    timerTCB0.cnt = TCB0.CNT;  // read out CNT first, then CCMP
    timerTCB0.ccmp = TCB0.CCMP;
    timerTCB0.finish = true;
    timerTCB0.DeleteFlagCAPT();  // clear the interrupt flag
  }

  ISR(TCB1_INT_vect) {
    timerTCB1.cnt = TCB1.CNT;  // read out CNT first, then CCMP
    timerTCB1.ccmp = TCB1.CCMP;
    timerTCB1.finish = true;
    timerTCB1.DeleteFlagCAPT();  // clear the interrupt flag
  }

  ISR(TCB3_INT_vect) {
    timerTCB3.cnt = TCB3.CNT;  // read out CNT first, then CCMP
    timerTCB3.ccmp = TCB3.CCMP;
    timerTCB3.finish = true;
    timerTCB3.DeleteFlagCAPT();  // clear the interrupt flag
  }
//}


void printBackground() {
  TFT.fillRect(0, 0, 320, 170, BG_COLOR);
  TFT.fillRect(164, 0, 3, 121, FG_COLOR);
  TFT.fillRect(0, 120, 320, 3, FG_COLOR);

  TFT.setTextColor(FG_COLOR);
  TFT.setTextSize(3);

  TFT.setCursor(173, 6);
  TFT.print(HS_TEXT);
  TFT.setCursor(173, 63);
  TFT.print(VS_TEXT);
  TFT.setCursor(263, 36);
  TFT.print(KHZ_TEXT);
  TFT.setCursor(282, 93);
  TFT.print(HZ_TEXT);

  //placeholder
  TFT.setCursor(173, 36);
  TFT.print("00.00");
  TFT.setCursor(191, 93);
  TFT.print("00.00");

  TFT.setTextSize(2);

  TFT.setCursor(6, 129);
  TFT.print(VD_TEXT);
  TFT.setCursor(6, 149);
  TFT.print(AD_TEXT);

  digitalWrite(CONVERTER_DETECT, HIGH);
  digitalWrite(CONVERTER_POWERSAVE, LOW);
  digitalWrite(VIDEO_AMP_BYPASS, LOW);
  digitalWrite(VIDEO_AMP_DISABLE, LOW);
}

void getTimings() {
  static uint32_t lastMillis{ 0 };

  if (timerTCB0.finish) {
    uint16_t period{ 0 };
    uint16_t pulse{ 0 };
    ATOMIC_BLOCK(ATOMIC_RESTORESTATE) {
      period = timerTCB0.cnt;
      pulse = timerTCB0.ccmp;
    }
    tempHorizontalFreq = 1 / (62.5 * 1.0 * (float)period / 1000000000UL) / 1000;
    tempHorizontalPos = 62.5 * 1.0 * (float)pulse / 1000UL;
    tempHorizontalNeg = (62.5 * 1.0 * (float)period / 1000UL) - tempHorizontalPos;
    timerTCB0.finish = false;

    timingHSyncTimer.Start();
  }

  if (timerTCB1.finish) {
    uint16_t period{ 0 };
    uint16_t pulse{ 0 };
    ATOMIC_BLOCK(ATOMIC_RESTORESTATE) {
      period = timerTCB1.cnt;
      pulse = timerTCB1.ccmp;
    }
    tempVerticalFreq = 1 / (62.5 * 64.0 * (float)period / 1000000000UL);
    tempVerticalPos = 62.5 * 64.0 * (float)pulse / 1000000UL;
    tempVerticalNeg = (62.5 * 64.0 * (float)period / 1000000UL) - tempVerticalPos;
    timerTCB1.finish = false;

    timingVSyncTimer.Start();
  }

  if (timerTCB3.finish) {
    uint16_t period{ 0 };
    uint16_t pulse{ 0 };
    ATOMIC_BLOCK(ATOMIC_RESTORESTATE) {
      period = timerTCB3.cnt;
      pulse = timerTCB3.ccmp;
    }
    tempInterlacedFreq = 1 / (62.5 * 64.0 * (float)period / 1000000000UL);
    tempInterlacedPos = 62.5 * 64.0 * (float)pulse / 1000000UL;
    tempInterlacedNeg = (62.5 * 64.0 * (float)period / 1000000UL) - tempInterlacedPos;
    timerTCB3.finish = false;

    timingOddEvenTimer.Start();
  }
}

void drawTimings() {

  int32_t dotIndex;

  TFT.setTextColor(FG_COLOR, BG_COLOR);
  TFT.setTextSize(3);

  if (!timings.locked || timings.horizontal == 0.0f || timings.vertical == 0.0f) {
    TFT.setCursor(173, 36);
    TFT.print("00.00");

    TFT.setCursor(191, 93);
    TFT.print("00.00");
    return;
  }

  String h;
  h = String(timings.horizontal);
  dotIndex = h.indexOf('.');
  h = h.substring(dotIndex - 2, 5);

  String v;
  v = String(timings.vertical);
  dotIndex = v.indexOf('.');
  v = v.substring(dotIndex - 2, 5);

  TFT.setCursor(173, 36);
  TFT.print(h);

  TFT.setCursor(191, 93);
  TFT.print(v);
}

void drawDiagTimings() {

  TFT.setTextColor(FG_COLOR, BG_COLOR);
  TFT.setTextSize(1);

  TFT.setCursor(0, 8);
  TFT.print(tempHorizontalFreq);
  TFT.setCursor(0, 16);
  TFT.print(tempHorizontalPos);
  TFT.setCursor(0, 24);
  TFT.print(tempHorizontalNeg);

  TFT.setCursor(0, 32);
  TFT.print(tempVerticalFreq);
  TFT.setCursor(0, 40);
  TFT.print(tempVerticalPos);
  TFT.setCursor(0, 48);
  TFT.print(tempVerticalNeg);

  TFT.setCursor(0, 56);
  TFT.print(tempInterlacedFreq);
  TFT.setCursor(0, 64);
  TFT.print(tempInterlacedPos);
  TFT.setCursor(0, 72);
  TFT.print(tempInterlacedNeg);
  
}

void setVideoPins() {

  //digitalWrite(VIDEO_AMP_DISABLE, HIGH);
  //delay(100);

  int8_t formatSetting = avSetting & 0b00000011;
  int8_t videoSetting = (avSetting & 0b00001100) >> 2;
  int8_t audioSetting = (avSetting & 0b00110000) >> 4;

  TFT.setTextColor(FG_COLOR, BG_COLOR);
  TFT.setTextSize(2);

  if (videoSetting == 1 && formatSetting == 0) {  // SCART - RGBS

    digitalWrite(VIDEO_MUX_1_SELECT, LOW);
    digitalWrite(VIDEO_MUX_2_SELECT, LOW);
    digitalWrite(VIDEO_MUX_1_ENABLE, LOW);
    digitalWrite(VIDEO_MUX_2_ENABLE, LOW);

    digitalWrite(CSYNC_MUX_1, HIGH);
    digitalWrite(CSYNC_MUX_2, LOW);

    digitalWrite(CONVERTER_SELECT, LOW);
    digitalWrite(CONVERTER_DETECT, HIGH);
    digitalWrite(CONVERTER_POWERSAVE, LOW);
  }
  else if (videoSetting == 1 && formatSetting == 1) {  // SCART - RGsB

    digitalWrite(VIDEO_MUX_1_SELECT, LOW);
    digitalWrite(VIDEO_MUX_2_SELECT, LOW);
    digitalWrite(VIDEO_MUX_1_ENABLE, LOW);
    digitalWrite(VIDEO_MUX_2_ENABLE, LOW);

    digitalWrite(CSYNC_MUX_1, HIGH);
    digitalWrite(CSYNC_MUX_2, HIGH);

    digitalWrite(CONVERTER_SELECT, LOW);
    digitalWrite(CONVERTER_DETECT, HIGH);
    digitalWrite(CONVERTER_POWERSAVE, LOW);
  }
  else if (videoSetting == 1 && formatSetting == 2) {  // SCART - YPbPr

    digitalWrite(VIDEO_MUX_1_SELECT, LOW);
    digitalWrite(VIDEO_MUX_2_SELECT, LOW);
    digitalWrite(VIDEO_MUX_1_ENABLE, LOW);
    digitalWrite(VIDEO_MUX_2_ENABLE, LOW);

    digitalWrite(CSYNC_MUX_1, HIGH);
    digitalWrite(CSYNC_MUX_2, HIGH);

    digitalWrite(CONVERTER_SELECT, HIGH);
    digitalWrite(CONVERTER_DETECT, HIGH);
    digitalWrite(CONVERTER_POWERSAVE, LOW);
  } 
  else if (videoSetting == 2 && formatSetting == 0) {  // VGA - RGBS

    digitalWrite(VIDEO_MUX_1_SELECT, HIGH);
    digitalWrite(VIDEO_MUX_2_SELECT, LOW);
    digitalWrite(VIDEO_MUX_1_ENABLE, LOW);
    digitalWrite(VIDEO_MUX_2_ENABLE, LOW);

    digitalWrite(CSYNC_MUX_1, LOW);
    digitalWrite(CSYNC_MUX_2, HIGH);
    digitalWrite(HSYNC_MUX_IN, LOW);
    digitalWrite(HSYNC_MUX_OUT, HIGH);

    digitalWrite(CONVERTER_SELECT, LOW);
    digitalWrite(CONVERTER_DETECT, HIGH);
    digitalWrite(CONVERTER_POWERSAVE, LOW);
  } 
  else if (videoSetting == 2 && formatSetting == 1) {  // VGA - RGsB

    digitalWrite(VIDEO_MUX_1_SELECT, HIGH);
    digitalWrite(VIDEO_MUX_2_SELECT, LOW);
    digitalWrite(VIDEO_MUX_1_ENABLE, LOW);
    digitalWrite(VIDEO_MUX_2_ENABLE, LOW);

    digitalWrite(CSYNC_MUX_1, HIGH);
    digitalWrite(CSYNC_MUX_2, HIGH);

    digitalWrite(CONVERTER_SELECT, LOW);
    digitalWrite(CONVERTER_DETECT, HIGH);
    digitalWrite(CONVERTER_POWERSAVE, LOW);
  } 
  else if (videoSetting == 2 && formatSetting == 2) {  // VGA - YPbPr

    digitalWrite(VIDEO_AMP_BYPASS, HIGH);
    digitalWrite(VIDEO_AMP_DISABLE, LOW);

    digitalWrite(VIDEO_MUX_1_SELECT, HIGH);
    digitalWrite(VIDEO_MUX_2_SELECT, LOW);
    digitalWrite(VIDEO_MUX_1_ENABLE, LOW);
    digitalWrite(VIDEO_MUX_2_ENABLE, LOW);

    digitalWrite(CSYNC_MUX_1, HIGH);
    digitalWrite(CSYNC_MUX_2, HIGH);

    digitalWrite(CONVERTER_SELECT, HIGH);
    digitalWrite(CONVERTER_DETECT, HIGH);
    digitalWrite(CONVERTER_POWERSAVE, LOW);
  } 
  else if (videoSetting == 2 && formatSetting == 3) {  // VGA - RGBHV

    digitalWrite(VIDEO_AMP_BYPASS, LOW);
    digitalWrite(VIDEO_AMP_DISABLE, LOW);
    digitalWrite(VIDEO_MUX_1_SELECT, HIGH);
    digitalWrite(VIDEO_MUX_2_SELECT, LOW);
    digitalWrite(VIDEO_MUX_1_ENABLE, LOW);
    digitalWrite(VIDEO_MUX_2_ENABLE, LOW);

    digitalWrite(CSYNC_MUX_1, LOW);
    digitalWrite(CSYNC_MUX_2, HIGH);
    digitalWrite(HSYNC_MUX_IN, HIGH);
    digitalWrite(HSYNC_MUX_OUT, LOW);

    digitalWrite(CONVERTER_SELECT, LOW);
    digitalWrite(CONVERTER_DETECT, HIGH);
    digitalWrite(CONVERTER_POWERSAVE, LOW);
  } 
  else if (videoSetting == 3 && formatSetting == 1) {  // COMP - RGsB

    digitalWrite(VIDEO_MUX_1_SELECT, HIGH);
    digitalWrite(VIDEO_MUX_2_SELECT, HIGH);
    digitalWrite(VIDEO_MUX_1_ENABLE, LOW);
    digitalWrite(VIDEO_MUX_2_ENABLE, LOW);

    digitalWrite(CSYNC_MUX_1, HIGH);
    digitalWrite(CSYNC_MUX_2, HIGH);

    digitalWrite(CONVERTER_SELECT, LOW);
    digitalWrite(CONVERTER_DETECT, HIGH);
    digitalWrite(CONVERTER_POWERSAVE, LOW);
  }
  else if (videoSetting == 3 && formatSetting == 2) {  // COMP - YPbPr

    digitalWrite(VIDEO_AMP_BYPASS, HIGH);
    digitalWrite(VIDEO_AMP_DISABLE, LOW);

    digitalWrite(VIDEO_MUX_1_SELECT, HIGH);
    digitalWrite(VIDEO_MUX_2_SELECT, HIGH);
    digitalWrite(VIDEO_MUX_1_ENABLE, LOW);
    digitalWrite(VIDEO_MUX_2_ENABLE, LOW);

    digitalWrite(CSYNC_MUX_1, HIGH);
    digitalWrite(CSYNC_MUX_2, HIGH);

    digitalWrite(CONVERTER_SELECT, HIGH);
    digitalWrite(CONVERTER_DETECT, HIGH);
    digitalWrite(CONVERTER_POWERSAVE, LOW);
  } 
  
  String videoInputName = "";

  if (videoSetting == 1) {
    videoInputName += "SCART";
  } 
  else if (videoSetting == 2) {
    videoInputName += "VGA";
  } 
  else if (videoSetting == 3) {
    videoInputName += "Component";
  }

  videoInputName += " - ";

  if (formatSetting == 0) {
    videoInputName += "RGBS";
  } 
  else if (formatSetting == 1) {
    videoInputName += "RGsB";
  } 
  else if (formatSetting == 2) {
    videoInputName += "YPbPr";
  } 
  else if (formatSetting == 3) {
    videoInputName += "RGBHV";
  }

  if(!settingsMenu) {
    TFT.fillRect(90, 129, 230, 16, BG_COLOR);
    TFT.setCursor(90, 129);
    TFT.print(videoInputName);
  }


  //delay(100);
  //digitalWrite(VIDEO_AMP_DISABLE, LOW);

  videoPinsSet = true;
}
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
void loop() {

  getTimings();

  if(!settingsMenu)
    drawTimings();
  else
    drawDiagTimings();

  if (!videoPinsSet)
    setVideoPins();

  if (!audioPinsSet)
    setAudioPins();

  if(timingHSyncTimer.IsRunning){
    if (timingHSyncTimer.ElapsedTime() > 100) {
      timingHSyncTimer.IsRunning = false;
      tempHorizontalFreq = 0.0f;
      tempHorizontalPos = 0.0f;
      tempHorizontalNeg = 0.0f;
    }
  }
  if(timingVSyncTimer.IsRunning){
    if (timingVSyncTimer.ElapsedTime() > 100) {
      timingVSyncTimer.IsRunning = false;
      tempVerticalFreq = 0.0f;
      tempVerticalPos = 0.0f;
      tempVerticalNeg = 0.0f;
    }
  }
  if(timingOddEvenTimer.IsRunning){
    if (timingOddEvenTimer.ElapsedTime() > 100) {
      timingOddEvenTimer.IsRunning = false;
      tempInterlacedFreq = 0.0f;
      tempInterlacedPos = 0.0f;
      tempInterlacedNeg = 0.0f;
    }
  }

  if(But1.ElapsedTime() > 1000) {
    if(!settingsMenu) {
      settingsMenu = true;

      TFT.fillRect(0, 0, 320, 170, BG_COLOR);
      But1.Reset();
    }
  }

  if (But1.WasPressed()) {
    selectedPreset++;

    if(selectedPreset >= 9)
      selectedPreset = 0;

    switch(selectedPreset){
      case 0: { avSetting = 0b00110100 ; break;}
      case 1: { avSetting = 0b00110101 ; break;}
      case 2: { avSetting = 0b00110110 ; break;}
      case 3: { avSetting = 0b00011000 ; break;}
      case 4: { avSetting = 0b00011001 ; break;}
      case 5: { avSetting = 0b00011010 ; break;}
      case 6: { avSetting = 0b00011011 ; break;}
      case 7: { avSetting = 0b00101110 ; break;}
      case 8: { avSetting = 0b00101101 ; break;}      
    }

    videoPinsSet = false;
    audioPinsSet = false;
    
  }

  if (But2.WasPressed()) {
    int8_t videoSetting = (avSetting & 0b00001100) >> 2;
    avSetting = avSetting & 0b11110000;

    if (videoSetting == 1) {
      avSetting = avSetting | 0b00001000;
    } else if (videoSetting == 2) {
      avSetting = avSetting | 0b00001110;
    } else if (videoSetting == 3) {
      avSetting = avSetting | 0b00000100;
    } else if (videoSetting == 0) {
      avSetting = avSetting | 0b00000100;
    }
    videoPinsSet = false;
  }

  if (But3.WasPressed()) {
    int8_t videoSetting = (avSetting & 0b00001100) >> 2;
    int8_t formatSetting = avSetting & 0b00000011;
    avSetting = avSetting & 0b11111100;

    if (videoSetting == 1) {  //SCART
      if (formatSetting == 0) {
        avSetting = avSetting | 0b00000001;
      } else if (formatSetting == 1) {
        avSetting = avSetting | 0b00000010;
      } else if (formatSetting == 2) {
        avSetting = avSetting | 0b00000000;
      }
    } 
    else if (videoSetting == 2) {  //VGA
      if (formatSetting == 0) {
        avSetting = avSetting | 0b00000001;
      } else if (formatSetting == 1) {
        avSetting = avSetting | 0b00000010;
      } else if (formatSetting == 2) {
        avSetting = avSetting | 0b00000011;
      } else if (formatSetting == 3) {
        avSetting = avSetting | 0b00000000;
      }
    } 
    else if (videoSetting == 3) {  //Component
      if (formatSetting == 2) {
        avSetting = avSetting | 0b00000001;
      } else if (formatSetting == 1) {
        avSetting = avSetting | 0b00000010;
      }
    }

    videoPinsSet = false;
  }

  if (But4.WasPressed()) {
    if(!settingsMenu){
      int8_t audioSetting = (avSetting & 0b00110000) >> 4;
      avSetting = avSetting & 0b11001111;

      if (audioSetting == 3) {
        avSetting = avSetting | 0b00010000;
      } else if (audioSetting == 2) {
        avSetting = avSetting | 0b00110000;
      } else if (audioSetting == 1) {
        avSetting = avSetting | 0b00100000;
      } else if (audioSetting == 0) {
        avSetting = avSetting | 0b00110000;
      }

      audioPinsSet = false;
    }
    else {
      settingsMenu = false;
      printBackground();
      videoPinsSet = false;
      audioPinsSet = false;
    }
  }

  But1.Read();
  But2.Read();
  But3.Read();
  But4.Read();


  timingSamples[tSampleIndex].horizontal = tempHorizontalFreq;
  timingSamples[tSampleIndex].vertical = tempVerticalFreq;
  timingSamples[tSampleIndex].interlaced = tempInterlacedFreq;

  tSampleIndex++;
  
  if(tSampleIndex >= 10){

    uint16_t errorCount = 0;
    float averageHSync = timingSamples[0].horizontal;
    float averageVSync = timingSamples[0].vertical;
    float averageInterlaced = timingSamples[0].interlaced;


    for(int i = 1; i < 10; i++){
      if(timingSamples[i].horizontal > timingSamples[0].horizontal * 1.3f || timingSamples[i].horizontal < timingSamples[0].horizontal * (1.3f/(pow(1.3f, 2))))
        errorCount++;
      
      averageHSync += timingSamples[i].horizontal;
      averageVSync += timingSamples[i].vertical;
      averageInterlaced += timingSamples[i].interlaced;
    }


    if(errorCount == 0){
      timings.horizontal = averageHSync / 10;
      timings.vertical = averageVSync / 10;
      timings.interlaced = averageInterlaced / 10;

      if(timings.vertical != 0.0f){
        float linecount = floor(timings.horizontal * 1000 / timings.vertical);
        if (timings.interlaced != 0)
          timings.setLinecount(linecount * 2 + 1);
        else
          timings.setLinecount(linecount);
      }
      else{
        timings.setLinecount(0);
      }
    }

    if(errorCount >= 1 || settingsMenu)
      timings.setLock(false);
    else{
      timings.setLock(true);
    }

    tSampleIndex = 0;
  }



// Debug Code
  /*TFT.setTextColor(FG_COLOR, BG_COLOR);
  TFT.setTextSize(1);
  TFT.setCursor(0, 0);
  TFT.print(millis());
  TFT.setCursor(0, 8);
  TFT.print(tempHorizontal);
  TFT.setCursor(0, 16);
  TFT.print(tempVertical);
  TFT.setCursor(0, 24);
  TFT.print(tempInterlaced);

*/

}
